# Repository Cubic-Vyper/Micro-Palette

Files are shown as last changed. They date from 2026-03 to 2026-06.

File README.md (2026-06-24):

# Micro-Palette
This device will scan the color of something when the button is pressed, display the name of the color and the color code (rgb), and it will light up an LED under a keyboard switch as the exatct color scaned. I'm making this because it's always so annoying trying to find the color of somthing irl and then use that in inkscape, so I thought this will be a fun chalange to solve that. 

Stasis Page PDF (cuz you would need an account to view the page): https://github.com/Cubic-Vyper/Micro-Palette/blob/f946c92044628488ba2a7e05cdcd6b13fcdf1a42/Stasis_ProjectPage-Micro%20Palette.pdf

Demo Video: [https://youtu.be/u-WEpDEmPeA](https://youtu.be/u-WEpDEmPeA)

 Bill of Materials

| Name | Purpose | Cost Per Item (USD) | Quantity | Total (USD) | Link | Distributor |
|---|---|---|---|---|---|---|
| Custom PCB | this will connect all the parts | $2.10 | 1 | $2.10 | [Link to Listing](https://jlcpcb.com/) | JLCPCB |
| 0.91-inch OLED Display | This will display the color values | $1.99 | 1 | $1.99 | [Link to Listing](https://www.aliexpress.us/item/3256810479037826.html) | Aliexpress |
| TCS34725 Color Sensor | This will detect the color of objects | $3.85 | 1 | $3.85 | [Link to Listing](https://www.aliexpress.us/item/3256807206040384.html) | Aliexpress |
| Seeed Studio XIAO RP2040 | This is the brains of the device | $3.99 | 1 | $3.99 | [Link to Listing](https://www.seeedstudio.com/XIAO-RP2040-v1-0-p-5026.html) | Seed Studio |
| SK6812 MINI-E LEDs | this will display the color | $0.06 | 2 | $0.12 | [Link to Listing](https://www.alibaba.com/product-detail/Reverse-Mount-6028-Rgb-Smd-Led_1600431875998.html) | Alibaba |
| M3 x 12mm Bolts | This will hold everything together | $0.05 | 4 | $0.20 | [Link to Listing](https://www.alibaba.com/product-detail/M1-6-M2-M2-5-M3_1601369820018.html) | Alibaba |
| Keyboard switch | This will control when the scan starts (when pressed) | $0.18 | 1 | $0.18 | [Link to Listing](https://www.alibaba.com/product-detail/Outemu-5-Pin-Silent-Honey-Peach_1601612452658.html) | Alibaba |
| Keycap | This will go on the switch | $0.80 | 1 | $0.80 | [Link to Listing](https://www.alibaba.com/product-detail/Professional-Manufacturer-for-Blank-Abs-Injection_1601714378360.html) | Alibaba |
| 3D Printed Case | This will hold everything | $0.00 | 1 | $0.00 | There isn't a link | I will print this |
| Shipping | |  |  | $5.47 | | |

**Total Cost:** $22.70

here is the Micro Palette fully assembled:



Micro-Palette

to assemble, first gather all of the parts:



add the assembled pcb to the case:



add the lid and screw it on:



Finally add the keycap:



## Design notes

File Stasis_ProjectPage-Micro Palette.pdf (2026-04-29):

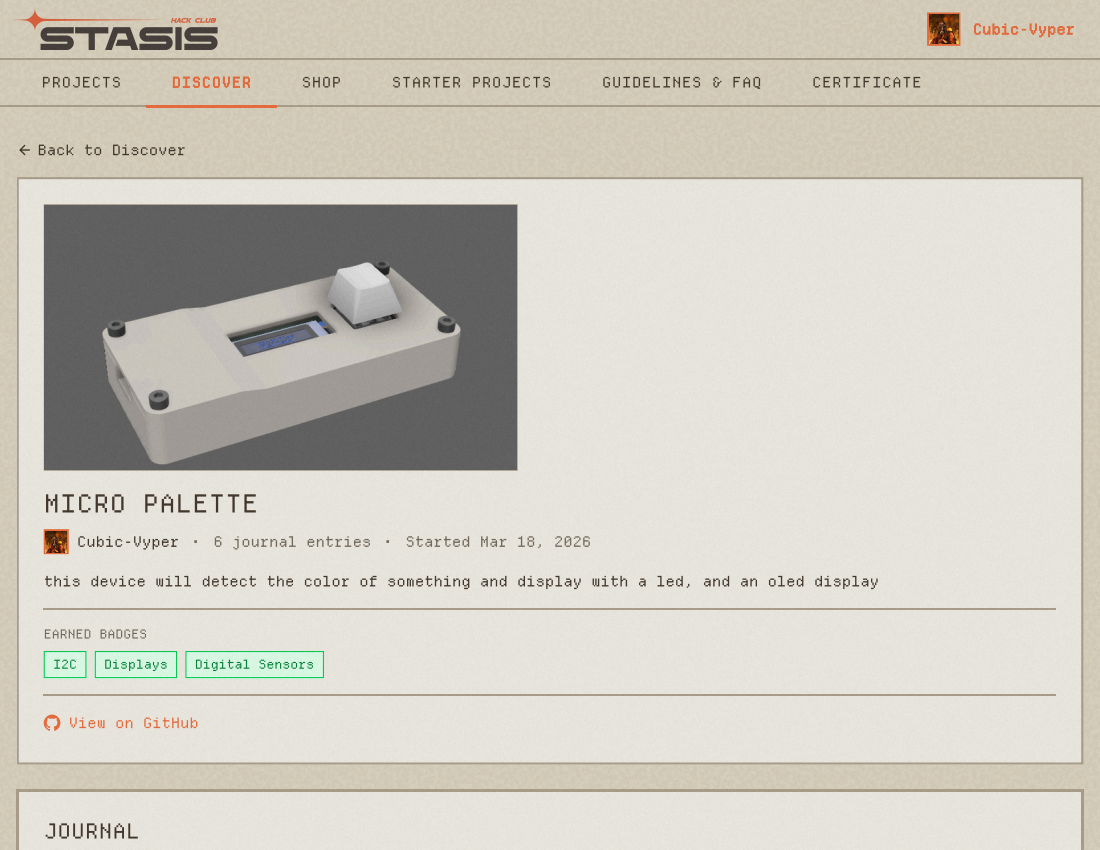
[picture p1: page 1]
PROJECTS; DISCOVER; SHOP; STARTER PROJECTS; GUIDELINES & FAQ; CERTIFICATE; MICRO PALETTE; EARNED BADGES; Displays; Digital Sensors; JOURNAL; Cubic-Vyper

Back to Discover (https://stasis.hackclub.com/dashboard/discover)

Cubic-Vyper (https://stasis.hackclub.com/dashboard/profile/ftxyx2WKc7q47xTXVjcz22hH0nWtcDV0) • 6 journal entries • Started Mar 18, 2026

this device will detect the color of something and display with a led, and an oled display

View on GitHub (https://github.com/Cubic-Vyper/Micro-Palette)

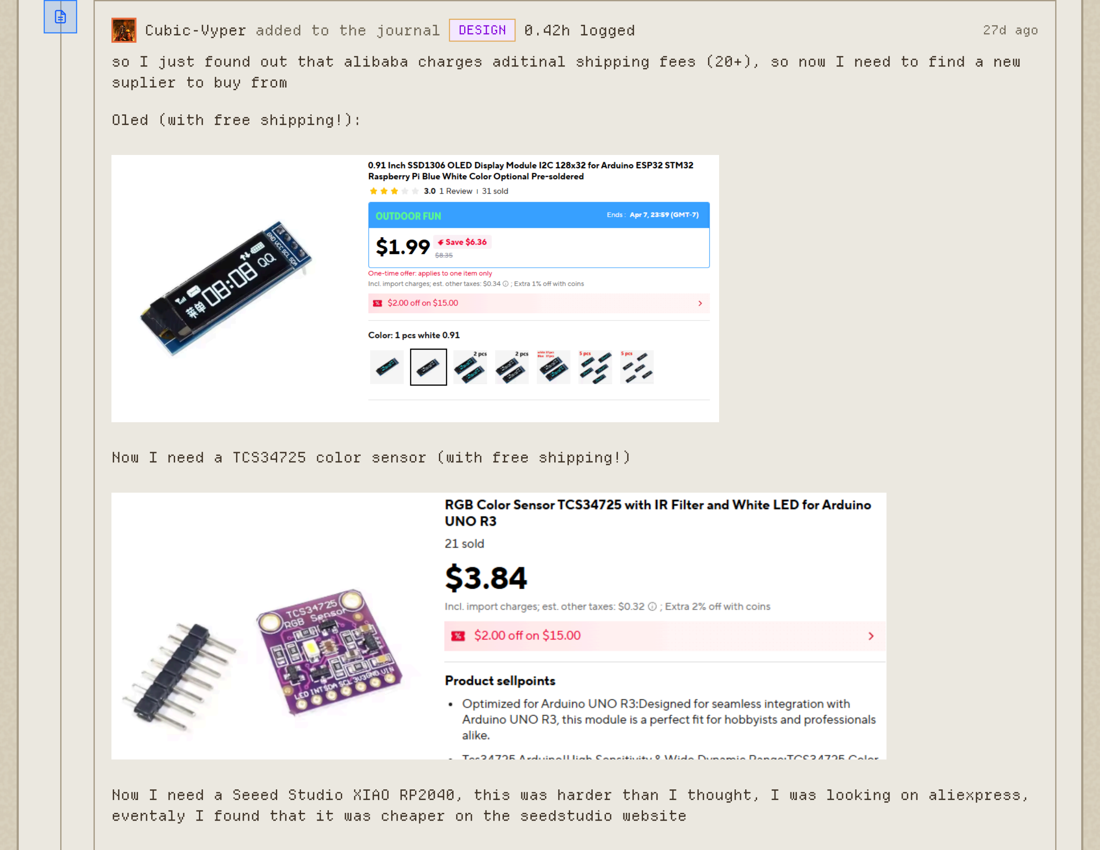
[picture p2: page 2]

Cubic-Vyper added to the journal | DESIGN | 0.42h logged | 27d ago

so I just found out that alibaba charges aditinal shipping fees (20+), so now I need to find a new

suplier to buy from

Oled (with free shipping!):

Now I need a TCS34725 color sensor (with free shipping!)

Now I need a Seeed Studio XIAO RP2040, this was harder than I thought, I was looking on aliexpress, eventaly I found that it was cheaper on the seedstudio website

and only $5.47 for shipping!

Cubic-Vyper added to the journal | DESIGN | 0.5h logged | Mar 22, 2026

Now I fix the code so that the scan will happen only when the button is pressed

I added the pin definition:

then the switch setup:

now i also changed this message from scanning to press button:

updating the main loop

I set the leds off on startup:

now I update the rest of the main loop:

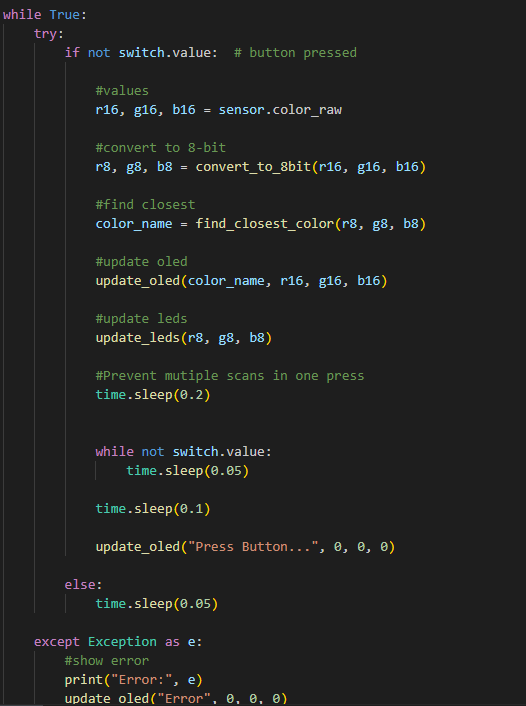
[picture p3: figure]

Cubic-Vyper added to the journal | DESIGN | 1.5h logged | Mar 21, 2026

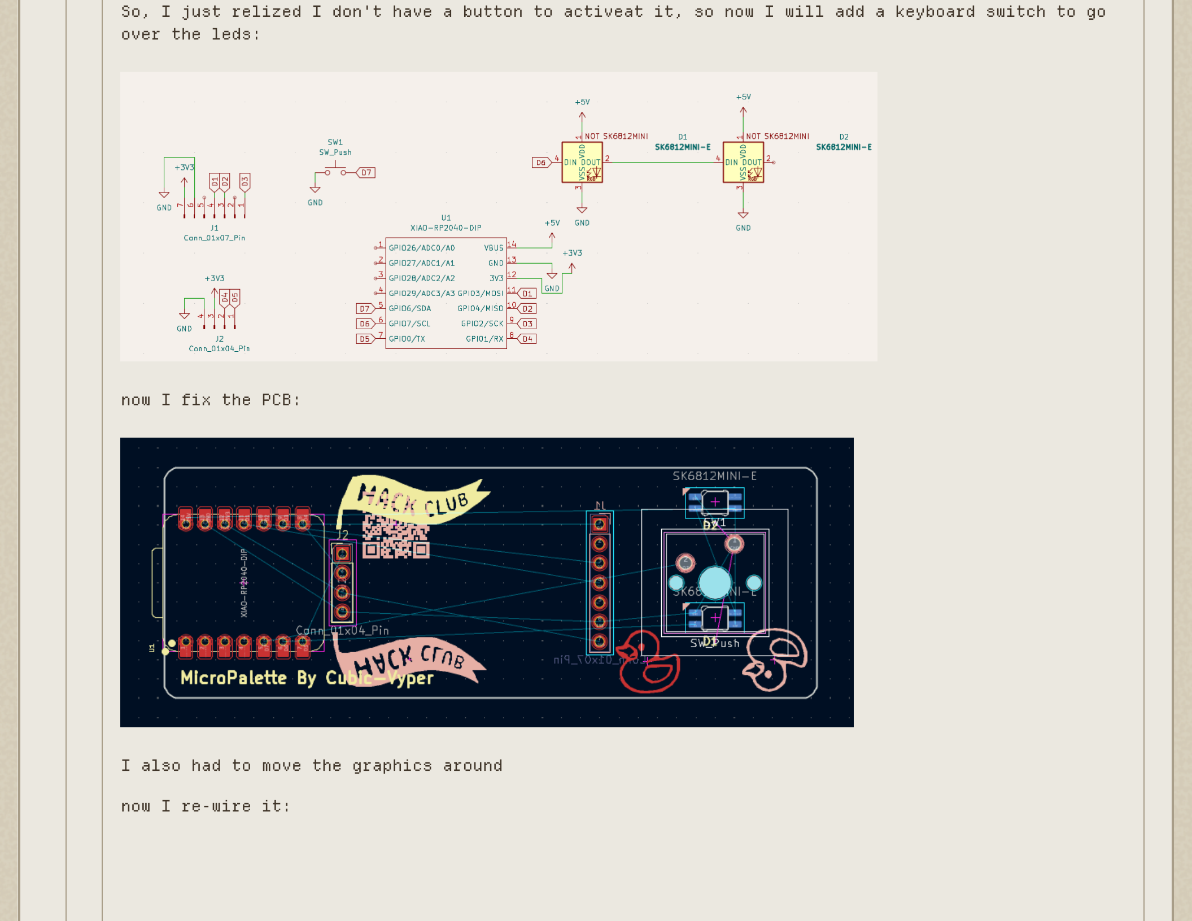
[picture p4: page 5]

So, I just relized I don't have a button to activeat it, so now I will add a keyboard switch to go

over the leds:

now I fix the PCB:

I also had to move the graphics around

now I re-wire it:

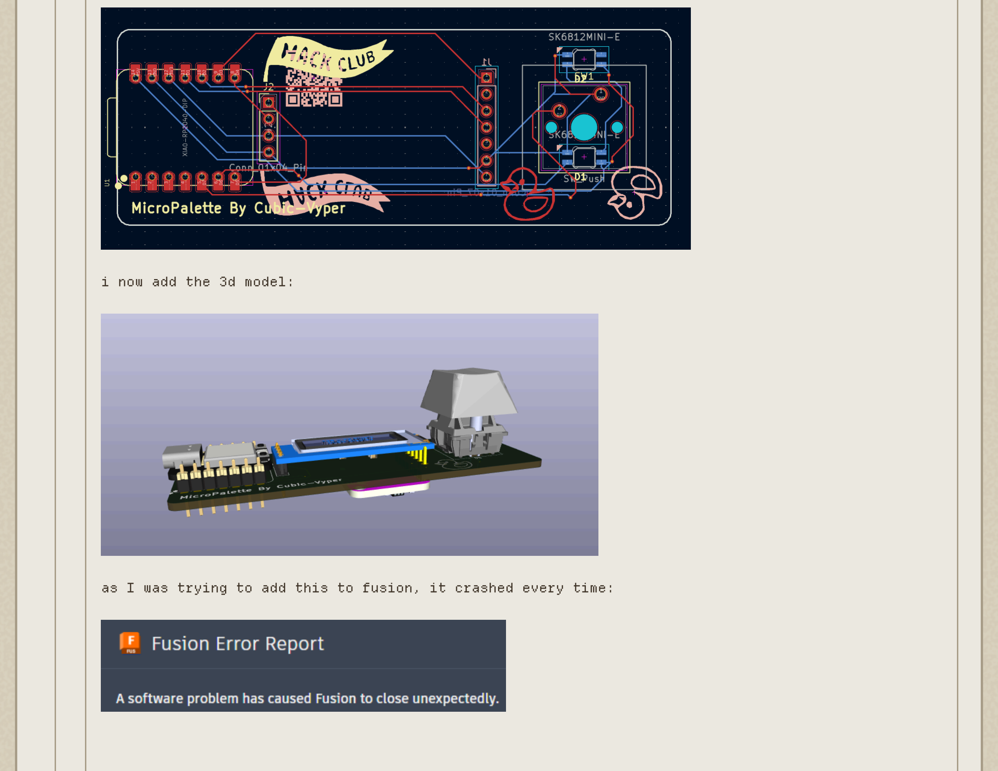
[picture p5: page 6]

i now add the 3d model:

as I was trying to add this to fusion, it crashed every time:

so far 5 times, it happens when I try to make the pcb solid insted of a suface, so it can stay a

surface :) (fiy fusion takes a few minutes to start):

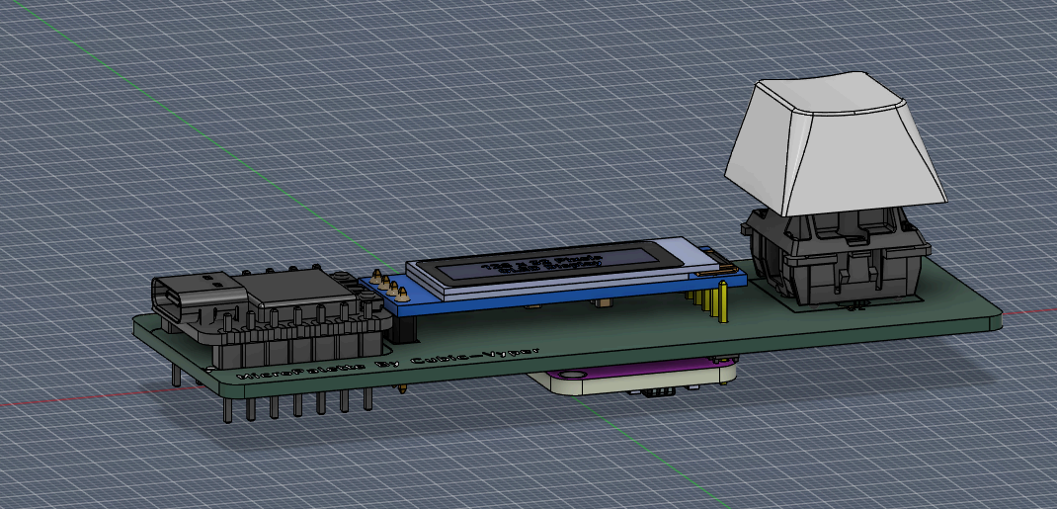
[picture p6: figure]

now I sketch where the hole for the switch will be:

and extrude:

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
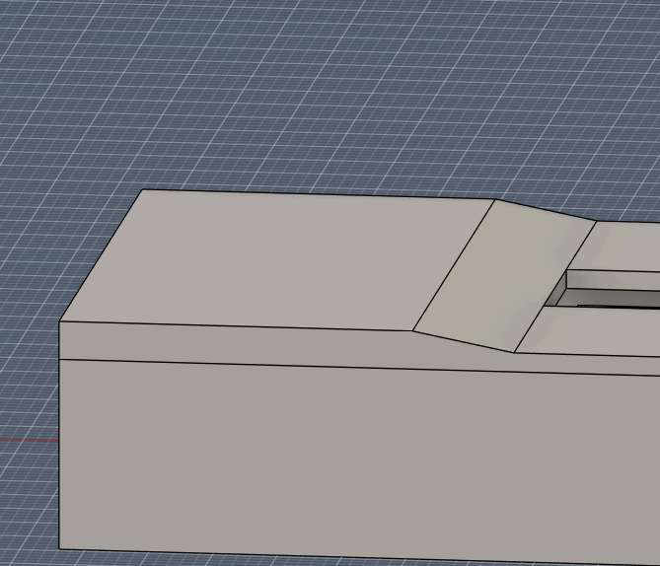
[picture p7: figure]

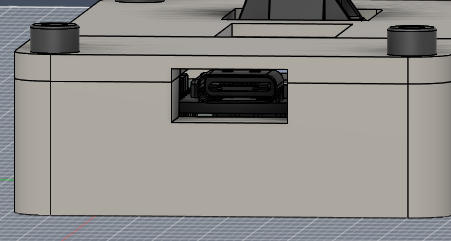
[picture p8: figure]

Cubic-Vyper added to the journal | DESIGN | 2h logged | Mar 20, 2026

I forgot to setup the timlapse so I will just explain my final code

first I import libarys:

Then define pins:

Then I start I2c comunication and turn on sensor:

Then I turn on the sensors led to light up the object (it will be in a dark case):

Then I start oled I2c, and start up the oled and leds:

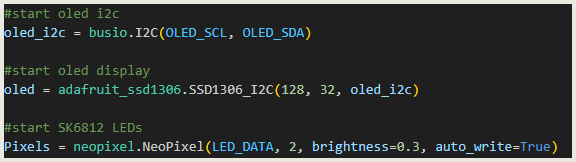
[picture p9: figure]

Next I define the known color codes(for oled to display):

This function converts the sensor's 16bit to 8bit:

This function finds the closest know color to display on the oled, but shows unkwn if unidentifiable:

This function displays the closest color name and the values(from scaned color - 16bit for more acurcy):

This updates the led with scaned color(in 8bit):

finaly, the main loop this scans the object and updates everything (and will show an error in needed)

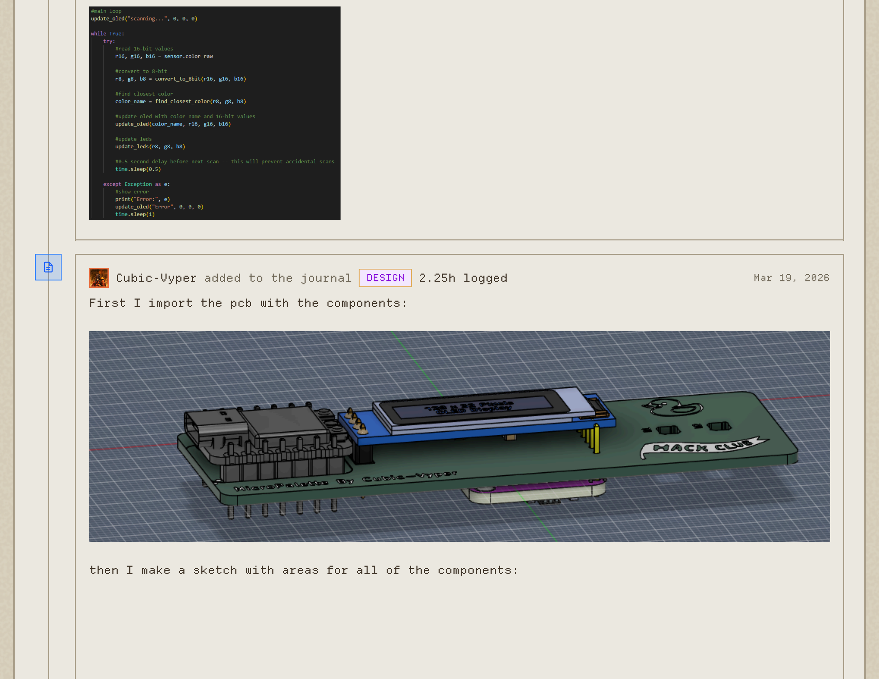
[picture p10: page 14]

Cubic-Vyper added to the journal | DESIGN | 2.25h logged | Mar 19, 2026

First I import the pcb with the components:

then I make a sketch with areas for all of the components:

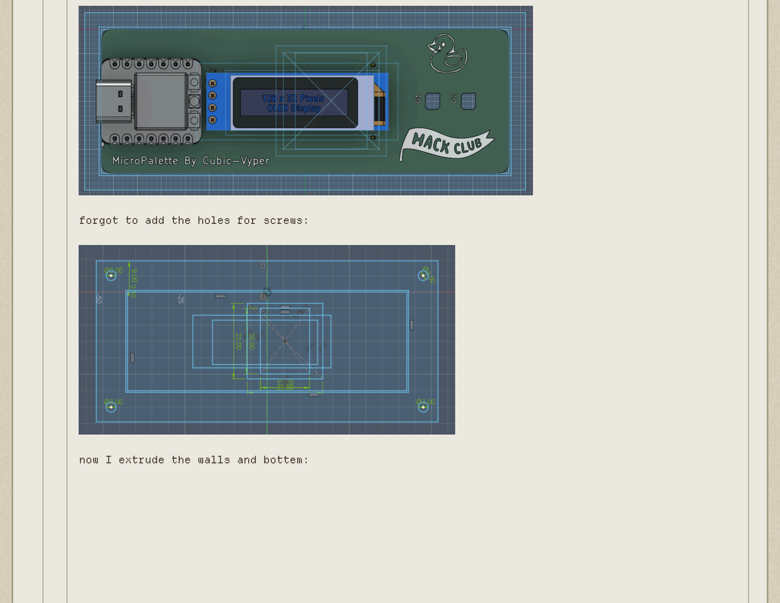
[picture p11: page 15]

forgot to add the holes for screws:

now I extrude the walls and bottem:

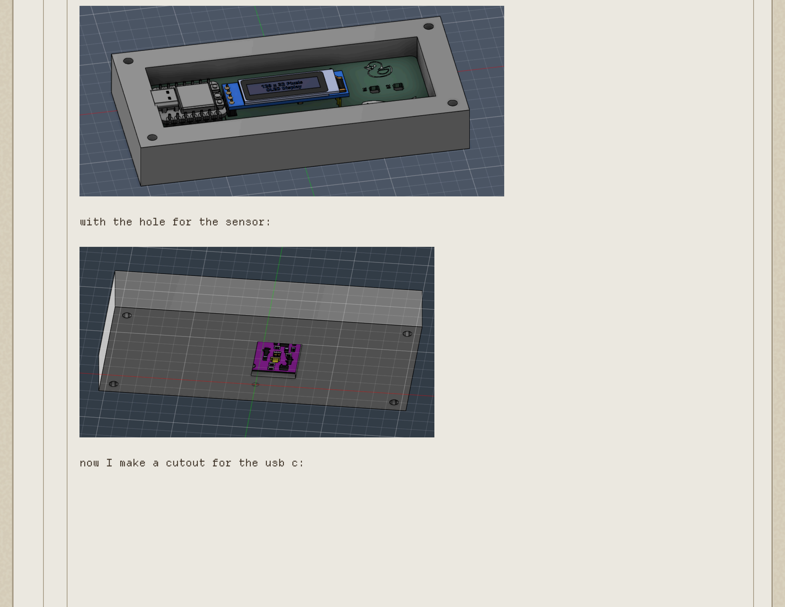
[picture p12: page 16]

with the hole for the sensor:

now I make a cutout for the usb c:

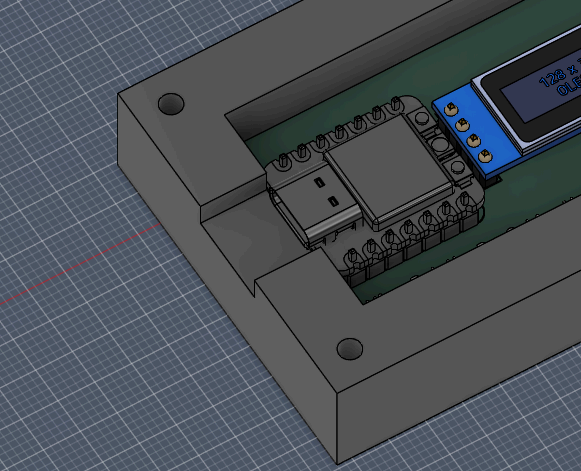
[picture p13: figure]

now I extrude the lid:

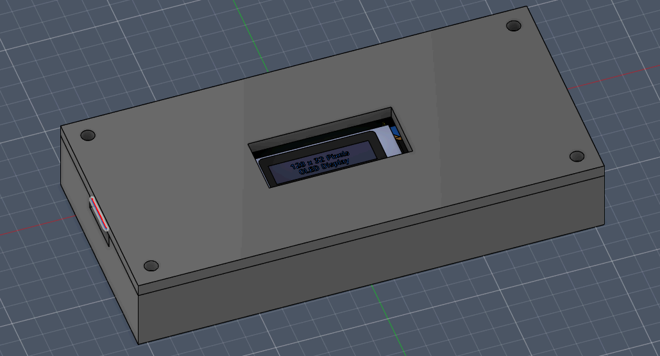
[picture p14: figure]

now I make another cutout for the usb c:

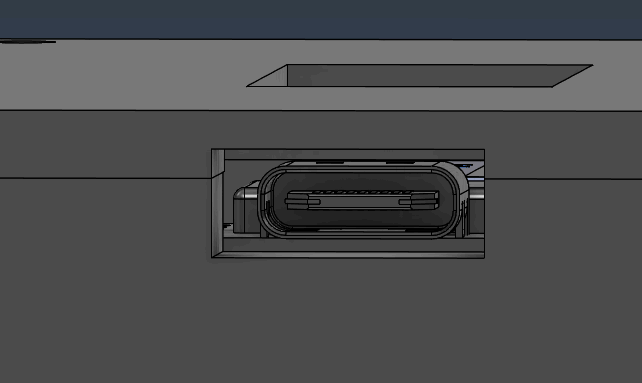
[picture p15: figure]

now I add these raisers for the pcb:

now I add this thin area to allow more light to come through:

now that area is only 1mm thick

here is the final case:

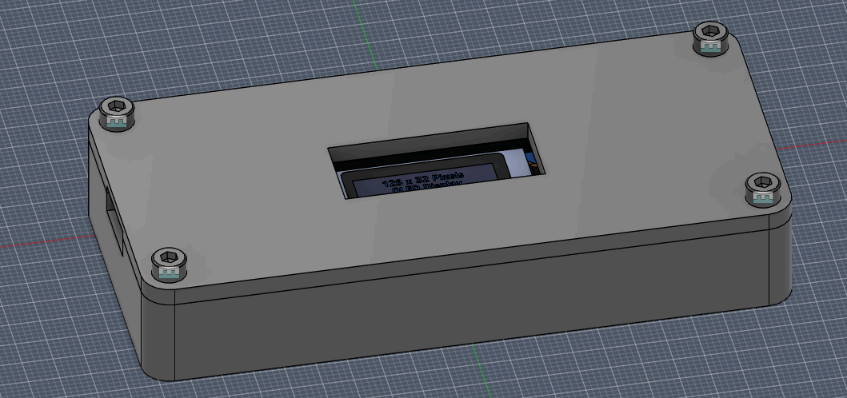
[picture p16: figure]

Cubic-Vyper added to the journal | DESIGN | 2.75h logged | Mar 19, 2026

First I import all my parts into my schematic, this took a while, I didn't know that pin headers where called Conn_01x04_Pin,

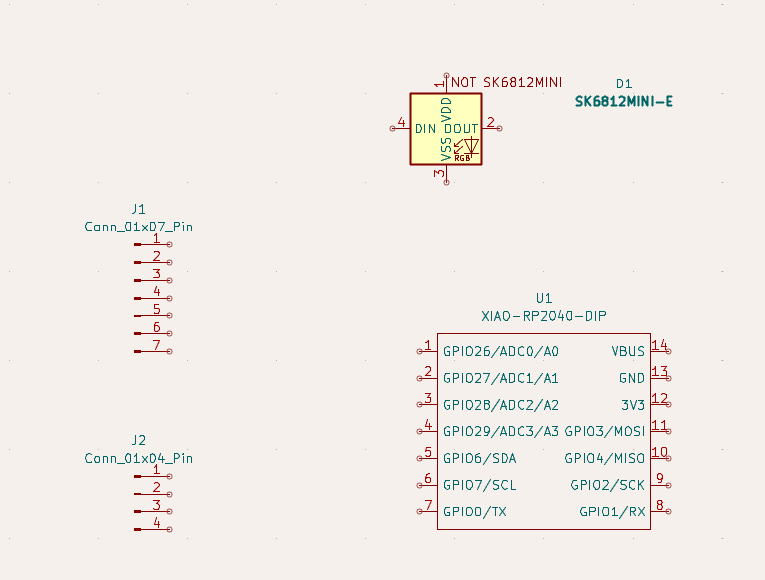
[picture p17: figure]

the 7pin header the the color sensor and the 4pin is the OLED

now I place all the power symbols

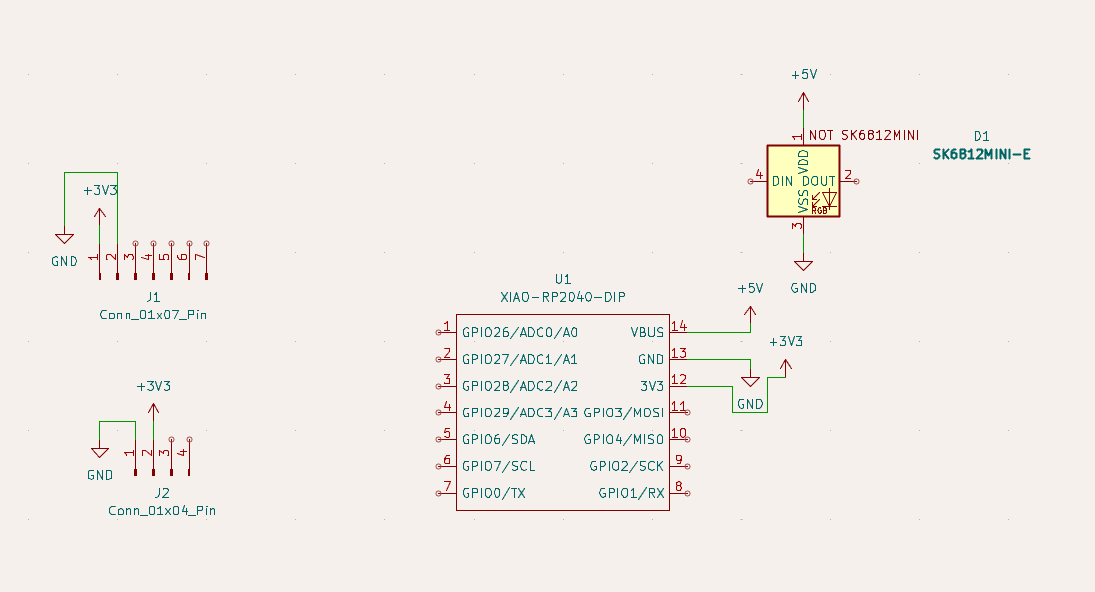
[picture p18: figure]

Now I wire all of my data pins:

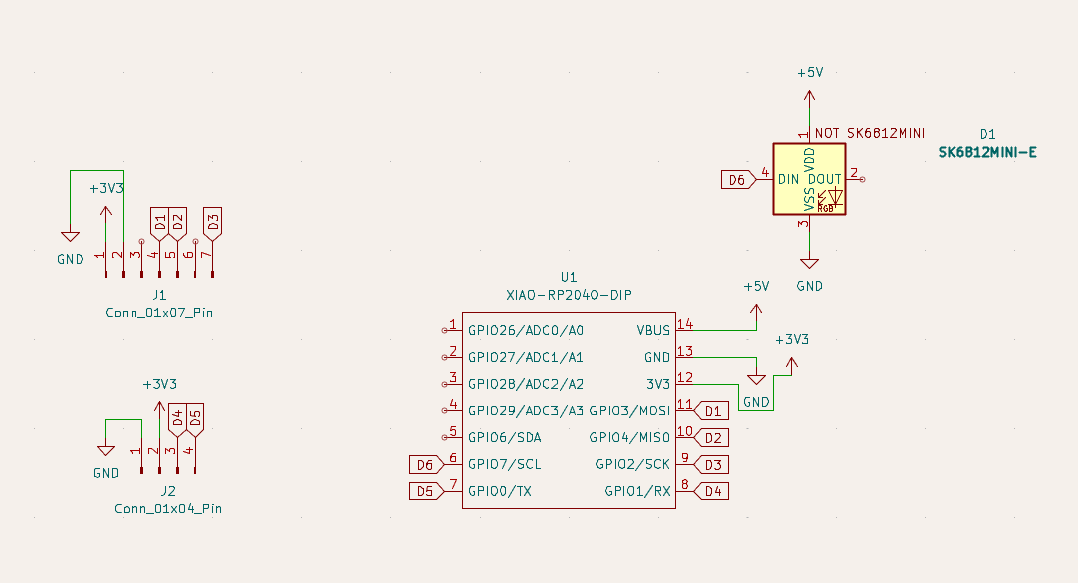
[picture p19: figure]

pin 3 (7pin header) is 3v3, i didn't wirre this because I already have it connected to VIN(pin 1), and pin 6 (7pin header) is INT, witch is unnneeded.

now I assign the footprints:

now I import the footprint into the pcb editor and move them around so everything will fit:

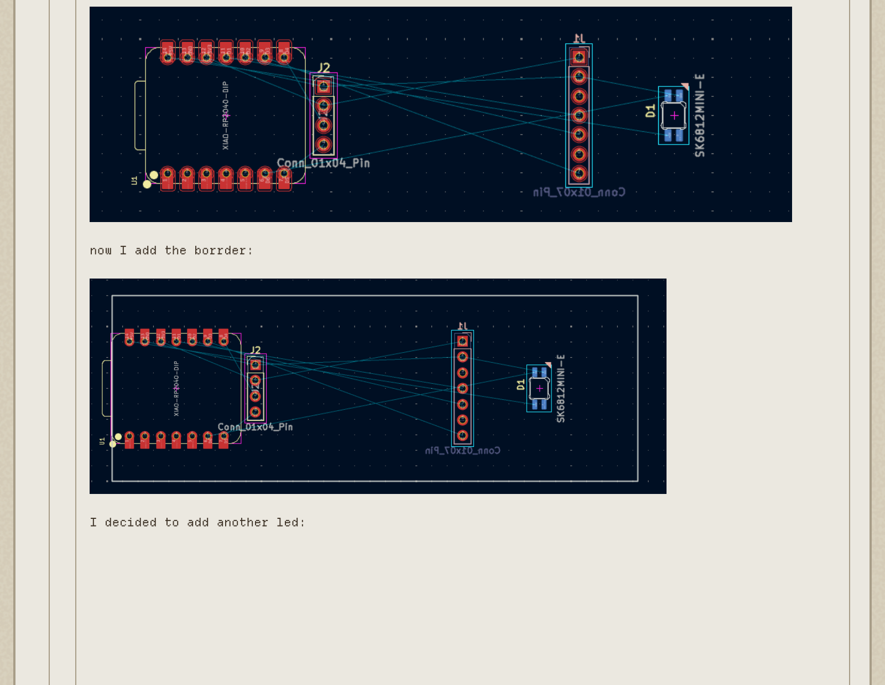
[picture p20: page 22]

now I add the borrder:

I decided to add another led:

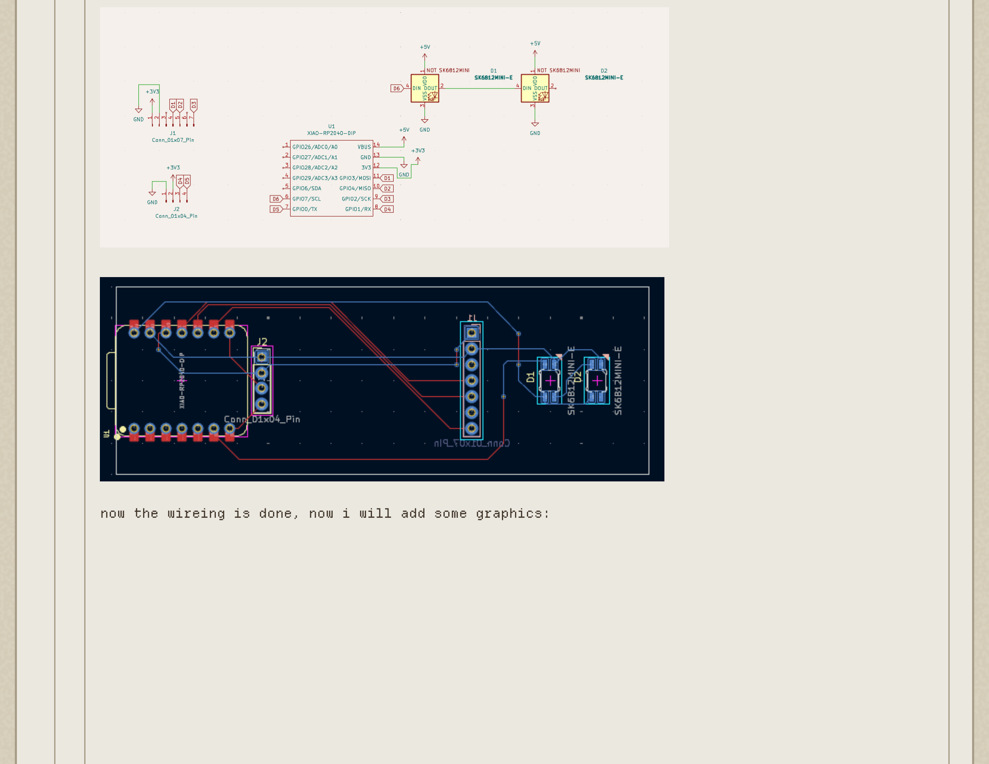
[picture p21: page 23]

now the wireing is done, now i will add some graphics:

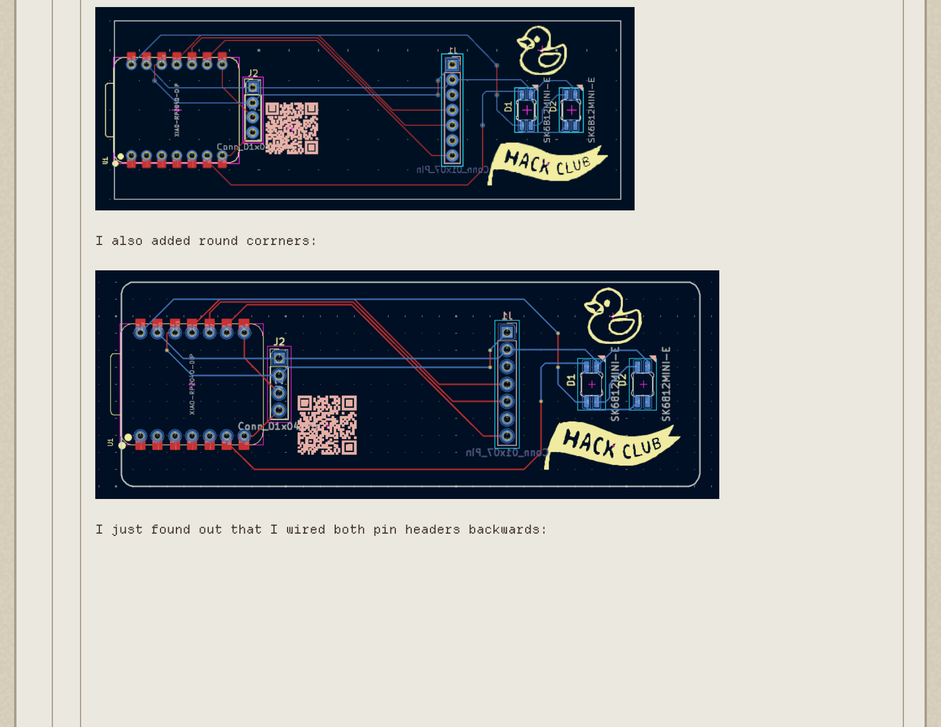
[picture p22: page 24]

I also added round corrners:

I just found out that I wired both pin headers backwards:

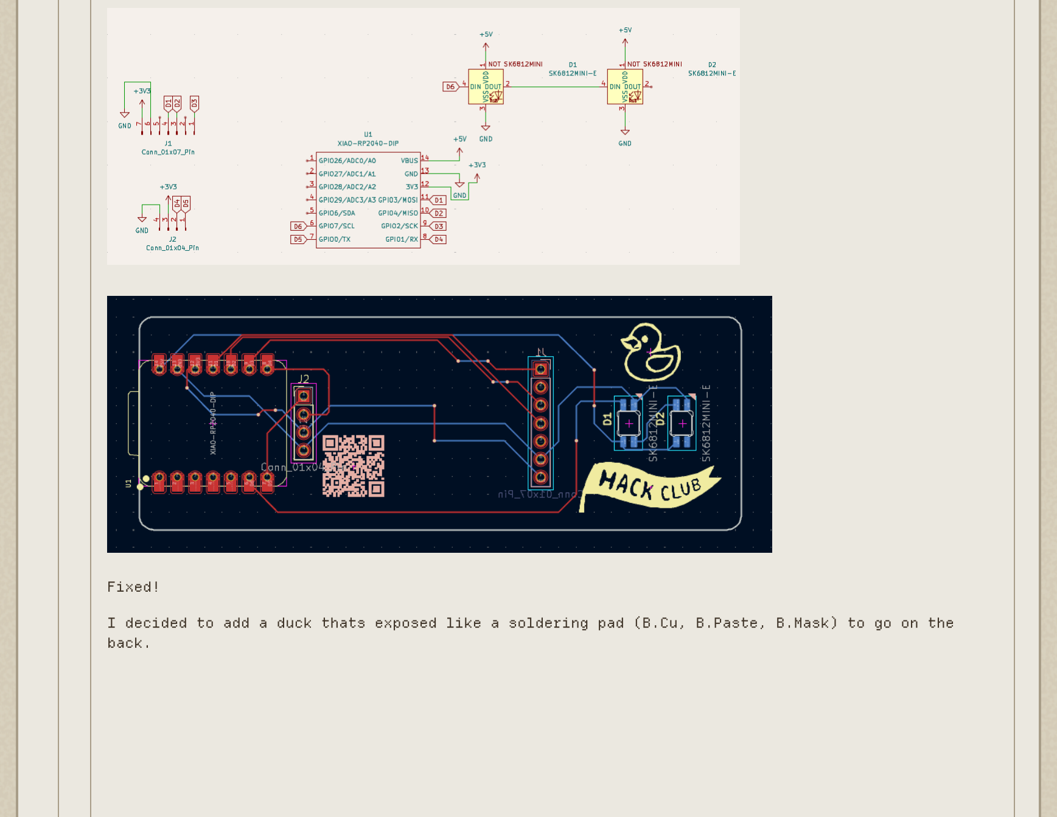
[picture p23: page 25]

Fixed!

I decided to add a duck thats exposed like a soldering pad (B.Cu, B.Paste, B.Mask) to go on the back.

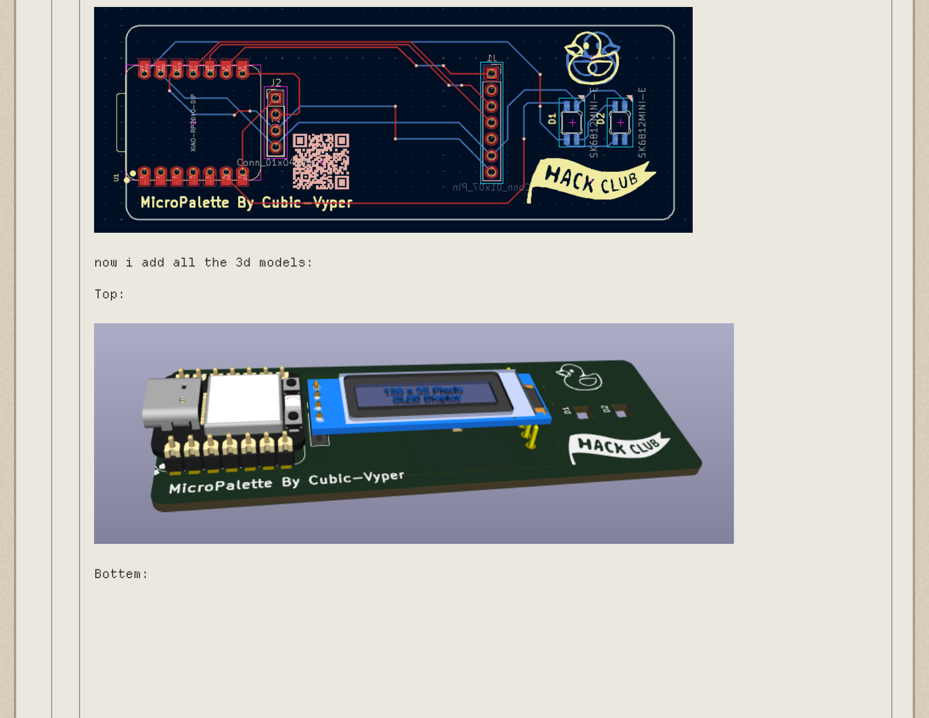
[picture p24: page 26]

now i add all the 3d models:

Top:

Bottem:

I also decided to add another flag to the back I also fliped the duck:

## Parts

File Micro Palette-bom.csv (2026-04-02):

Name | Purpose | Cost Per Item (USD) | Quantity | Total (USD) | Link | Distributor
Custom PCB | this will connect all the parts | $2.10 | 1 | $2.10 | https://jlcpcb.com/ | JLCPCB
0.91-inch OLED Display | This will display the color values | $1.99 | 1 | $1.99 | https://www.aliexpress.us/item/3256810479037826.html?mp=1 | Aliexpress
TCS34725 Color Sensor | This will detect the color of objects | $3.85 | 1 | $3.85 | https://www.aliexpress.us/item/3256807206040384.html?mp=1 | Aliexpress
Seeed Studio XIAO RP2040 | This is the brains of the device | $3.99 | 1 | $3.99 | https://www.seeedstudio.com/XIAO-RP2040-v1-0-p-5026.html | Seed Studio
SK6812 MINI-E LEDs | this will display the color | $0.06 | 2 | $0.12 | https://www.alibaba.com/product-detail/Reverse-Mount-6028-Rgb-Smd-Led_1600431875998.html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 | Alibaba
M3 x 12mm Bolts | This will hold everything together | $0.05 | 4 | $0.20 | https://www.alibaba.com/product-detail/M1-6-M2-M2-5-M3_1601369820018.html | Alibaba
Keyboard switch | This will control when the scan starts (when pressed) | $0.18 | 1 | $0.18 | https://www.alibaba.com/product-detail/Outemu-5-Pin-Silent-Honey-Peach_1601612452658.html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 | Alibaba
Keycap | This will go on the switch | $0.80 | 1 | $0.80 | https://www.alibaba.com/product-detail/Professional-Manufacturer-for-Blank-Abs-Injection_1601714378360.html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 | Alibaba
3D Printed Case | This will hold everything | $0.00 | 1 | $0.00 | There isn't a link | I will print this
Shipping |  |  |  | $5.47

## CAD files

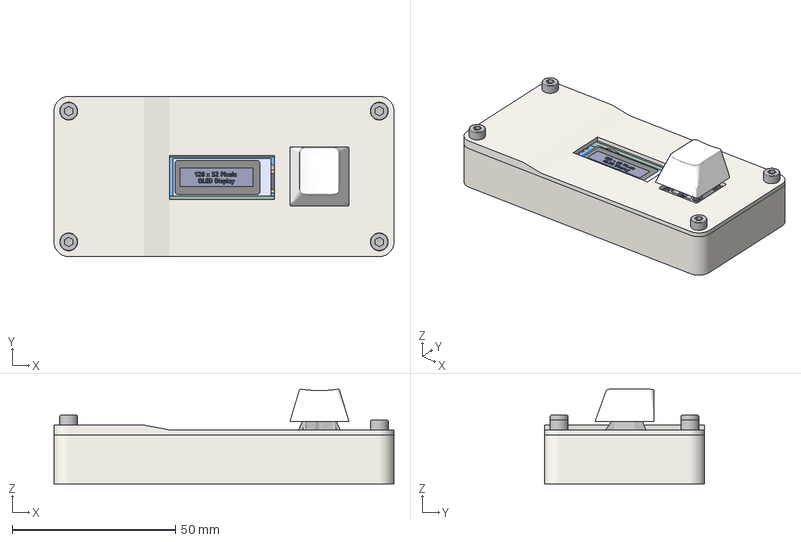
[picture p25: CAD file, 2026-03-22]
CAD/Micro-Palette_assembled.3mf
104.0 x 49.0 x 29.0 mm
Bottem
Top

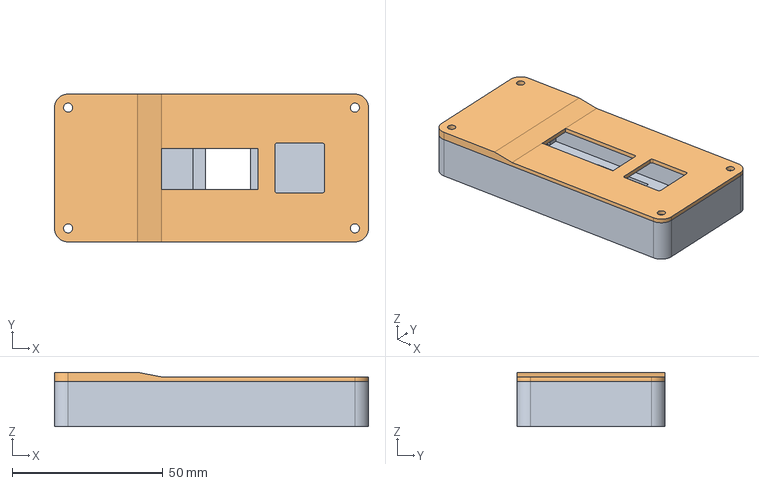
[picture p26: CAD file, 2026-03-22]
CAD/Micro-Palette_case.step
104.0 x 49.0 x 18.0 mm
Bottem
Top

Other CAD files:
CAD/Micro-Palette_case.3mf

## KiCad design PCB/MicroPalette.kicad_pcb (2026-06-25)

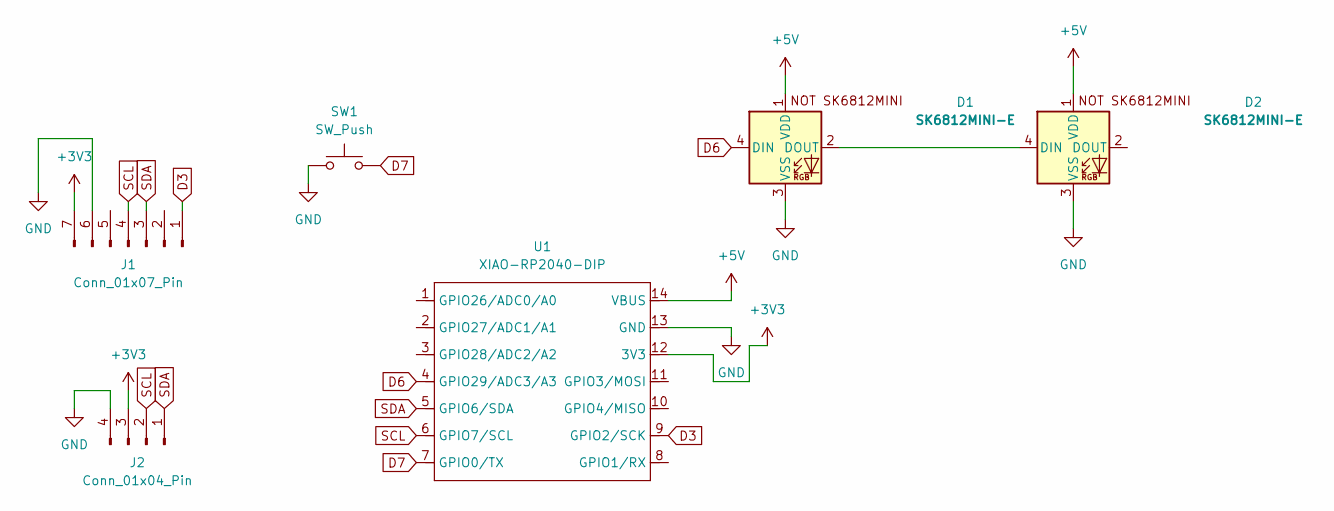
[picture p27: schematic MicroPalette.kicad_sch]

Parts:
D1, D2: SK6812MINI-E; SK6812MINI-E_fixed
J1: Conn_01x07_Pin; PinHeader_1x07_P2.54mm_Vertical
J2: Conn_01x04_Pin; PinHeader_1x04_P2.54mm_Vertical
SW1: SW_Push; SW_Cherry_MX_1.00u_PCB
U1: XIAO-RP2040-DIP

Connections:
+3V3: J1.7, J2.3, U1.12 (3V3)
+5V: D1.1 (VDD), D2.1 (VDD), U1.14 (VBUS)
D3: J1.1, U1.9 (GPIO2/SCK)
D6: D1.4 (DIN), U1.4 (GPIO29/ADC3/A3)
D7: SW1.2, U1.7 (GPIO0/TX)
GND: D1.3 (VSS), D2.3 (VSS), J1.6, J2.4, SW1.1, U1.13 (GND)
unnamed: D1.2 (DOUT), D2.4 (DIN)
SCL: J1.4, J2.2, U1.6 (GPIO7/SCL)
SDA: J1.3, J2.1, U1.5 (GPIO6/SDA)

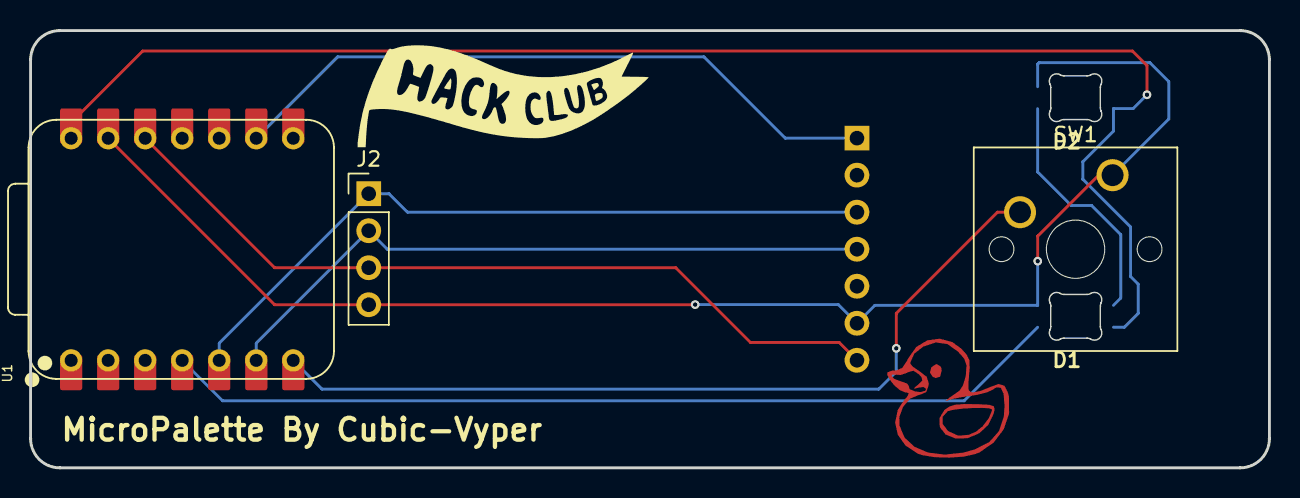
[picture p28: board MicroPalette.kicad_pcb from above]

Board: 2 copper layers, 85.0 x 30.0 mm, 6 parts (1 on the bottom side), 9 nets.

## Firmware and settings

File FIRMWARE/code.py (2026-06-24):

import board
import busio
import time
import neopixel
import adafruit_tcs34725
import adafruit_ssd1306
import digitalio  


#define pins

# I2C pins (sensor and oled)
I2C_SDA = board.D4
I2C_SCL = board.D5

#sensor led (illuminates object)
SENSOR_LED = board.D8

#SK6812 pin
LED_DATA = board.D3

#Switch pin
SWITCH_PIN = board.D6

# start i2c 
i2c = busio.I2C(I2C_SCL, I2C_SDA)

#start color sensor
sensor = adafruit_tcs34725.TCS34725(i2c)
sensor.integration_time = 50  #sensor collection time
sensor.gain = 4  

#turn on sensor LED 
sensor_led = digitalio.DigitalInOut(SENSOR_LED)
sensor_led.direction = digitalio.Direction.OUTPUT
sensor_led.value = True  
print("sensor LED on")

#Switch setup
switch = digitalio.DigitalInOut(SWITCH_PIN)
switch.direction = digitalio.Direction.INPUT
switch.pull = digitalio.Pull.UP

#start oled display
oled = adafruit_ssd1306.SSD1306_I2C(128, 32, i2c)   

#start SK6812 LEDs
pixels = neopixel.NeoPixel(LED_DATA, 2, brightness=0.3, auto_write=True)

#color codes
COLORS = {
    "red":     (255,  80, 107),
    "green":   (111, 255, 160),
    "blue":    ( 75, 149, 255),
    "yellow":  (255, 197, 122),
    "cyan":    (100, 232, 255),
    "pink": (255, 112, 172),
    "orange":  (255, 129, 103),
    "purple":  (190, 154, 255),
    "white":   (255, 253, 253),
    "gray": (212, 253, 255),
    "black":   (  0,   0,   0),
}


def find_closest_color(r8, g8, b8, r16, g16, b16):
    closest_name = "unknown"
    smallest_distance = 999999

    #compare color
    for name, (cr, cg, cb) in COLORS.items():
        #calculate color difference
        distance = (r8 - cr) ** 2 + (g8 - cg) ** 2 + (b8 - cb) ** 2
        
        if distance < smallest_distance:
            smallest_distance = distance
            closest_name = name

    #only return color name if it's close enough 
    if smallest_distance > 20000: 
        return "unknown"
    if closest_name == "white" and max(r16, g16, b16) < 2500:
        return "gray"

    return closest_name

def update_oled(color_name, r8, g8, b8):
    #clear display 
    oled.fill(0)
    
    #show color name 
    oled.text(color_name, 0, 0, 1)
    
    #show 8-bit RG values 
    oled.text(f"R:{r8:3d} G:{g8:3d}", 0, 12, 1)
    
    #show 8-bit blue value
    oled.text(f"B:{b8:3d}", 0, 22, 1)
    
    #update display
    oled.show()

def update_leds(r8, g8, b8):
    pixels.fill((r8, g8, b8))

# normalize color

WB_R = 4607
WB_G = 3628
WB_B = 2082


def normalize_color(r, g, b):

    r_bal = r / WB_R
    g_bal = g / WB_G
    b_bal = b / WB_B

    if max(r_bal, g_bal, b_bal) < 0.08:
        return (0, 0, 0)

    max_bal = max(r_bal, g_bal, b_bal)
    r8 = min(255, int((r_bal / max_bal) * 255))
    g8 = min(255, int((g_bal / max_bal) * 255))
    b8 = min(255, int((b_bal / max_bal) * 255))

    return r8, g8, b8


#main loop
update_oled("Press Button...", 0, 0, 0)

#turn off LEDs
pixels.fill((0, 0, 0))

while True:
    try:
        if not switch.value:  # button pressed

            #values
            r16, g16, b16, _ = sensor.color_raw
            r8, g8, b8 = normalize_color(r16, g16, b16)
            
            #find closest
            color_name = find_closest_color(r8, g8, b8, r16, g16, b16)

            #update oled
            update_oled(color_name, r8, g8, b8)
        
            #update leds    
            update_leds(r8, g8, b8)

            #Prevent mutiple scans in one press
            time.sleep(0.2)
            
            while not switch.value:
                time.sleep(0.05)
            
            time.sleep(0.1)
            
            
            
        else:
            time.sleep(0.05)

    except Exception as e:
        #show error
        print("Error:", e)
        update_oled("Error", 0, 0, 0)
        time.sleep(1)

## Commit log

2026-03-19 Update Micro Palette-bom.csv
    [Micro Palette-bom.csv]
2026-06-25 Add files via upload
    fixed pcb, sda/scl was wrong in the previous version
    [MicroPalette.kicad_pcb, MicroPalette.kicad_sch]
